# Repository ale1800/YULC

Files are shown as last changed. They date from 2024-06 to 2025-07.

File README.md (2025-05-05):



# YULC (Yes, a USB-C Led Controller)

## Current hw rev: [2.2](https://github.com/ale1800/YULC/blob/main/HW_VERSIONS.md)

## Available [here](https://aaelectronics-shop.com/)!

## You can find [here](https://aaelectronics-docs.com/documentation/yulc/yulc.html) the complete documentation.

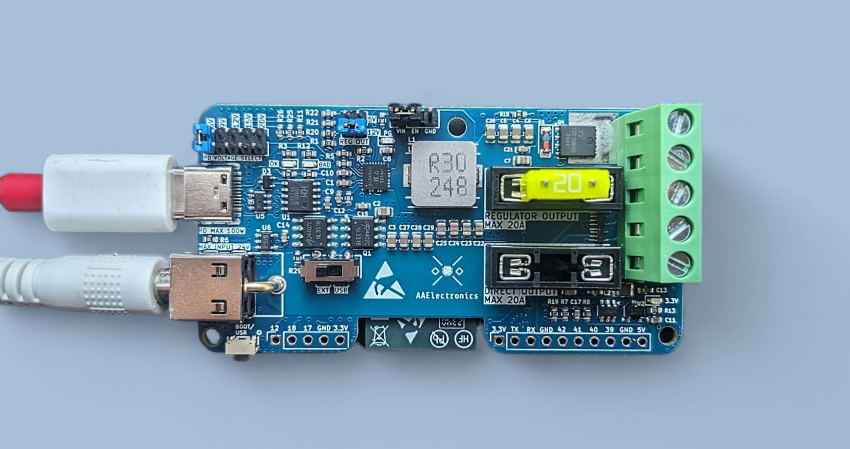
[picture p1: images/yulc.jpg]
yulc

**YULC** is your future-proof perfect mate for powering your lightings at 5, 12 or 24V. Thanks to its compact form factor, it can be placed almost everywhere, it features a lot of protections to **ensure safety for both the charger and the strips**, and in the meanwhile, **can provide a lot of juice to feed very power-hungry lights setup.** 
It also boasts an handy **built-in buck regulator** that from a maximum of 24V ensures safe 5V or 12V to your output. This mean that is also possible to use 18,19,...,24V external power supply (USB-C or barrel jack) taking advantage of their higher total power output and converting them to 5V or 12V increasing the output current.
Furthermore, on the back of the board there is a **powerful ESP32-S3, directly programmable from the USB-C**, that allows you to manage even more complex effects and to run heavy tasks.  
So, in few words, **YULC** consists in a full-featured board that can replace a lot of wiring messes, optimizing space and debug time in a reliable way.

## HOW IT WORKS

Here you can have a look to how the power path works:

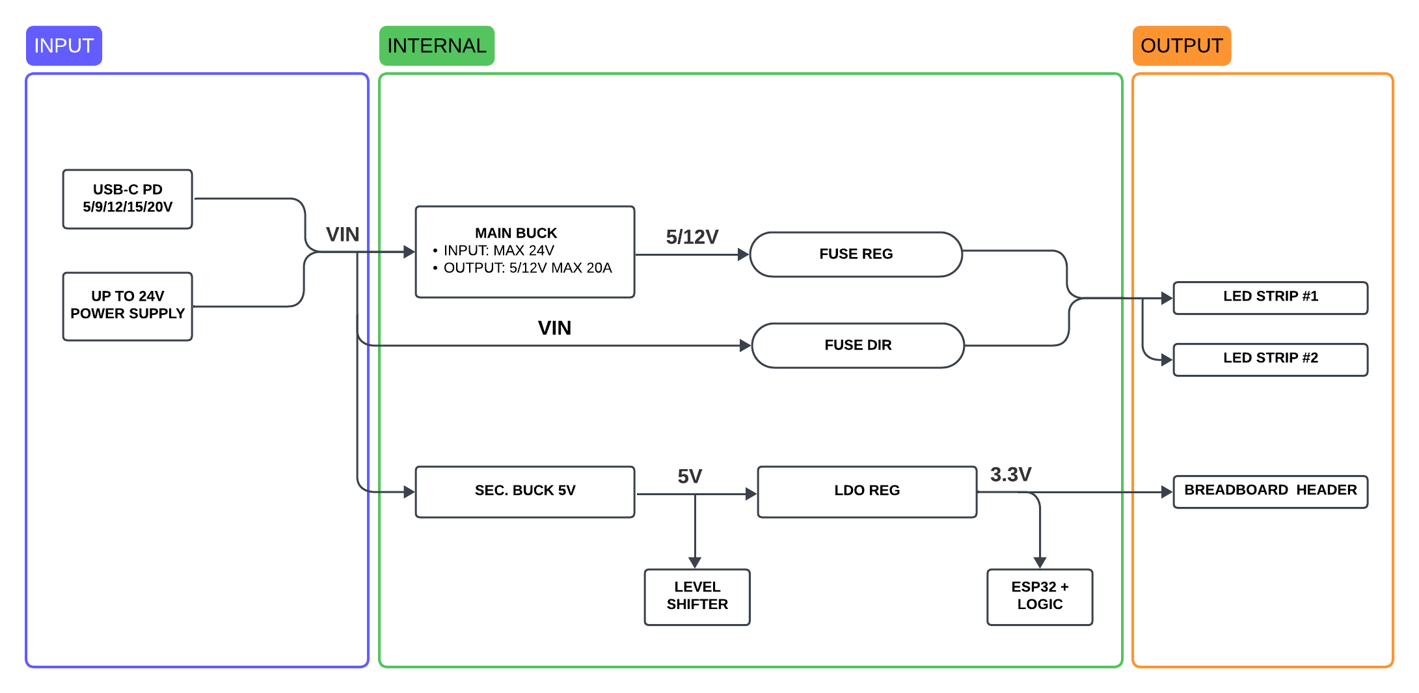
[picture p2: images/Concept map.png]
Concept map (6)


There are two power stages. The main one for the led stips and one dedicated to the ESP32

Powering all the logic and the ESP32-S3 with a dedicated secondary power stage without relying on the main one ensures that in case of a blowing fuse, everyhitng will still work as expected. So replacing the fuse on-the-fly will be the only thing you'll need to be again ready to go.

## YULC SETTINGS EXPLANATION

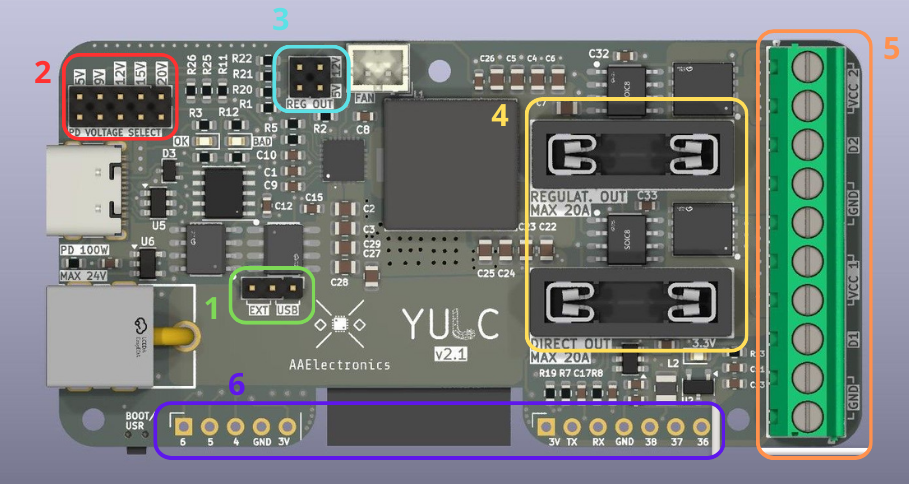
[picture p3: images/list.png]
Board


1) This is the main jumper that you have to select before anything else and before powering the board. If you join the **"EXT"** pins, YULC will be powered through the barrel jack power supply, not through the USB-C. So you can use a power supply up to 24V and then decide if you want to buck it to 5V or 12V or use it directly to the output bypassing the buck converter. With this selection, you are also able to safely program YULC through the USB-C while powering everything from the external power supply thanks to a back-to-back mosfet configuration. To do that **you have to select 5V from the PD selection voltage (2)**. There will also be those 5V on the board but they won't power anything (To prove that just disconnect the barrel jack power supply and the board will be turned off).
Instead, if you select **"USB"** pins, everything will be powered from the USB-C according to the voltage selected. 
As before, you can choose to buck the voltage to 12 or 5V or use it directly.
> [!CAUTION] 
**When selecting "USB", do not also connect the barrel jack!**.
   
2) USB-C PD Voltage selection. **Note that these voltages are the one you are asking for to the charger, not the ones you'll surely have on the board.** Selecting 20V, if the charger can provide them, the negotiation will end successfully, mosfets will let current flow and everything will be powered on. But if the charger is not able to do that, the negotiation will fail and the board will stay off. To help you debug that, the leds "OK" or "BAD" will lights up according to the negotiation result. Pay attention to the chargers you want to use. It should have a label with the list of voltages it can provide, so be sure to ask for that supported voltages, otherwise the negotiation will fail. Also consider the amount of power you need for your led strips and the power the charger can give.
**Chargers with the USB-A output will not work, even selecting 5V on YULC. Only Type-C Power Delivery chargers are compatible**
> [!IMPORTANT]  
Eg. If you have 5V strips like WS2812b and you want 6A at the output (so 30W), **be sure to ask the for a voltage/current combo the charger can offer that can give those 30W and than buck it to 5V through the converter to have the current you want at the output.**

> [!IMPORTANT]  
Be sure to select the closest combination of power and input voltage to what you need. If you need the buck IC to regulate at 5V, an input voltage of 9V or 12V will be better than a 24V from the heating point of view. The voltage difference (Vin - Vout) is smaller, so the inductor is "less stressed" -> less ripple current -> less heat. So you need the best trade-off with a quite close input voltage and enough power for your application.

3) This is the buck converter output regulation. Populate horizontally the pairs of pins according to the voltage you want to have at the output. If your input is lower or same as the output, just do not use the buck converter and route it directly but keep it populated even if you don't use it. The buck IC will automatically enter in an energy save mode when the load is really small or even is not present.
**The same voltage will be shared across the two channels**
You can source up to 20A from the IC.
> [!IMPORTANT]  
**With high watts at the output the board's temperature will increase, so please always use the given heatsinks (both for the IC and the inductor) and the 5V fan to be on the safe side.**

4) These two fuse holders are not one for channel as it could seem. The two channels share the same fuse. But there are two fuses because you have to select only one at a time according to what output you need. If you need the buck converter you have to populate the **"REGULAT. OUT"** fuse. Otherwise, if you want the input voltage routed directly to the output, populate the **"DIRECT OUT"** one.
These holders are compatible with both the standard automotive blade fuses and the mini blase fuses, but for higher currents the standard blade fuse is suggested thanks to a better contact with the holder's metal
> [!CAUTION]  
**Never populate both of them at the same time, it will short the regulator IC**.

5) YULC's has 10 output terminals, 5 for each channel: **2x Positive terminal, 2x GND terminal, 1x Data terminal**.     
Each terminal can handle up to 15A, so it's heavily suggested to use both the pairs of the positive terminal and negative terminal, to decrease the overall resistance and to inject power easier later in the strips.
Each channel is equipped with a level shifer to its data output and a high side power N-mosfet, in order to save a lot of power for longer strips in the idle state. These mosfets can also be used to control simpler strips through PWM, so you can easily control different combinations of type of strips using both the channels. **Plase attach the given heatinsks to them to keep them cool when switching high currents**

6) YULC exposes also some pins through breadboard-friendly headers. You can use these to connect buttons/microhpones/potentiometers but you can also increase the number of output channels but consider that they don't have level shifters and that you should take the power from the dedicated output terminals
   
 **GPIO Header:**
  
  |   Pin    |  Function |
  |----------|-----------|
  |  GPIO 6 |     IO    |
  |  GPIO 5 |     IO    |
  |  GPIO 4 |     IO    |
  |  GPIO 38 |     IO    |
  |  GPIO 37 |     IO    |
  |  GPIO 36 |     IO    |
  |  3V      |   Power   |
  |  GND     |  Ground   |
  |  GPIO 44   |    TX     |
  |  GPIO 43   |    RX     |
  
 **Used GPIO:**

  | Pin | Function |
  | --- | ---|
  | GPIO 0 (DO) | Boot/User Button |
  |  GPIO 1 (DO) | Led Data 1 |
  |  GPIO 2 (DO) | Led Data 2 |
  |  GPIO 47 (DO) | Mosfet 1 |
  | GPIO 21 (DO) | Mosfet 2 |
  | GPIO 7 (AI) | Fuse sense |

## YULC'S FISRT CONFIGURATION

According to your type of setup, you'll want to set YULC and strips to be powered in the the best way possibile.
Follow this steps to determine all the jumpers selection you need according to how [they work](#yulc-settings-explanation):
  
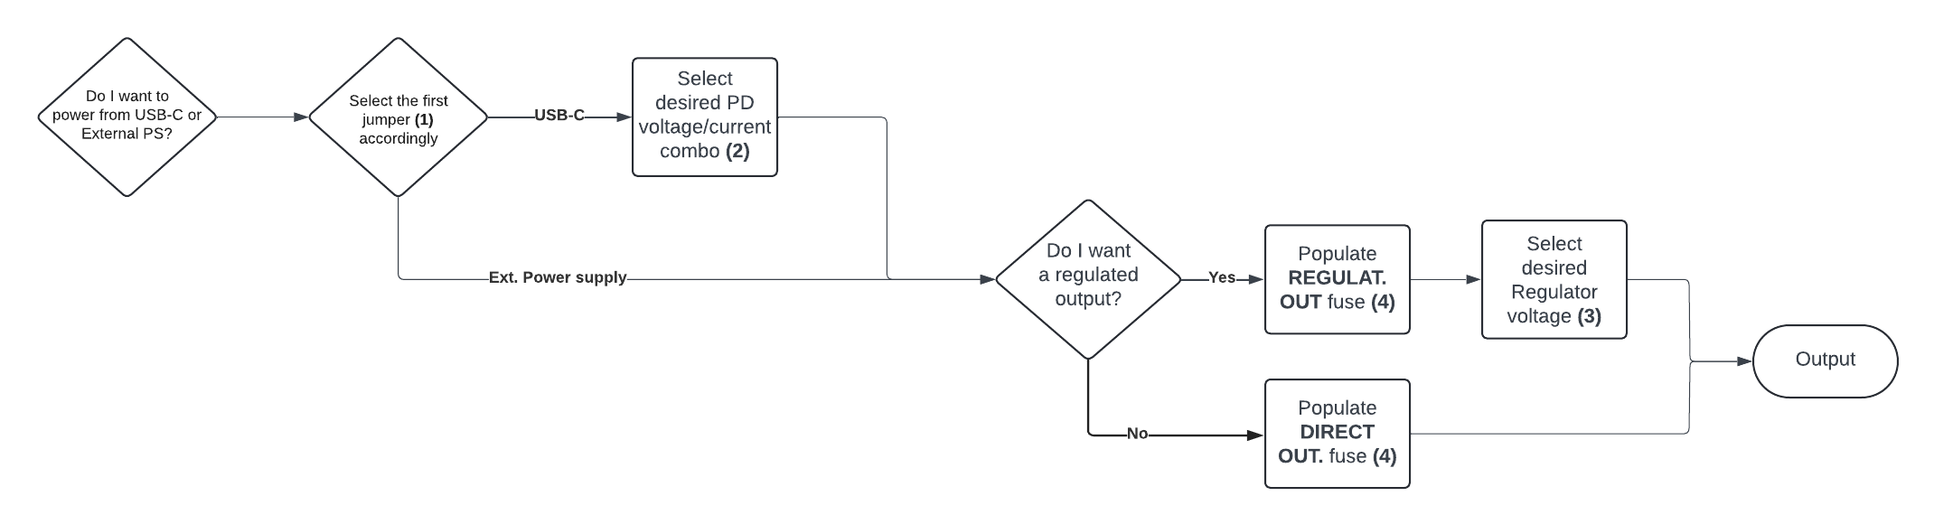
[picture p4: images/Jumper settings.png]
Settings_flow


> [!WARNING]  
**Be sure to power YULC only after you've set everything up, do not change PD and buck output voltages on the fly, neither the first jumper**

**Only after you are done with jumpers and fuse selections you can mount the [3D printed enclosure](https://github.com/ale1800/YULC/blob/main/ENCLOSURES.md), because once it's mounted, you'll have limited access to them.**

## SOFTWARE CONFIGURATION
- **YULC with [WLED](#wled)**
- ...

### WLED
Wled for YULC is a manually compiled build, based on the **v0.15.0-b5 "Kosen"**. It features 2 usermods: [Audio Reactive](https://kno.wled.ge/advanced/audio-reactive/) and [MultiRelay](https://mm.kno.wled.ge/usermods/MultiRelay/).

<center>
   <p>
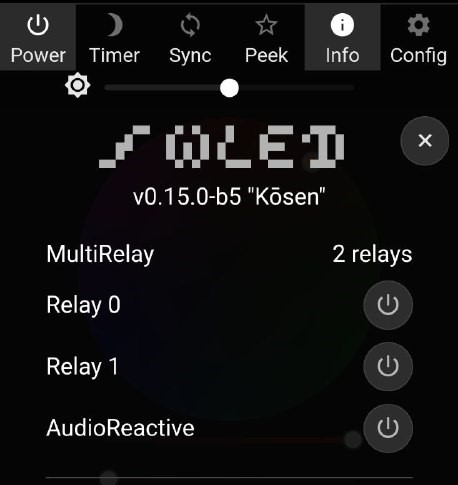
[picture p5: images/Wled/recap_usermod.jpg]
       
   </p>
</center>

**AUDIO REACTIVE**
 
Thanks to the powerful ESP32-S3, you can really take adavantage of this integration while driving complex effects on really long strip. Yuo have multiple pins on the exposed header that you can use to read an I2S microphone.

**MULTI RELAY**

Natively WLED only support one pin (usually connected to a relay) to physically turn on and off the light strips. While you can always use one of the exposed pins to wire an external relay, the built-in hardware already allows you to drive the two channels independently and each with its own power mosfet to toggle the strips. And thanks to this usermod, you can fully take advantage of it.
This is valid if you want to connect two addressable strips, but, for example, if you want to connect one digital strip and an anlog one, WLED already manage this without any external software. You would only need to set one mosfet as the main relay, and the other one as a PWM driving signal.
YULC offers a great versatility from this point of view.

So, to configure two digital strip go to **Config -> LED Preferences** and set everything up like the following picture with your own strips type and lengths. Also check **"Make a segment for each output"**
<center>
<p>
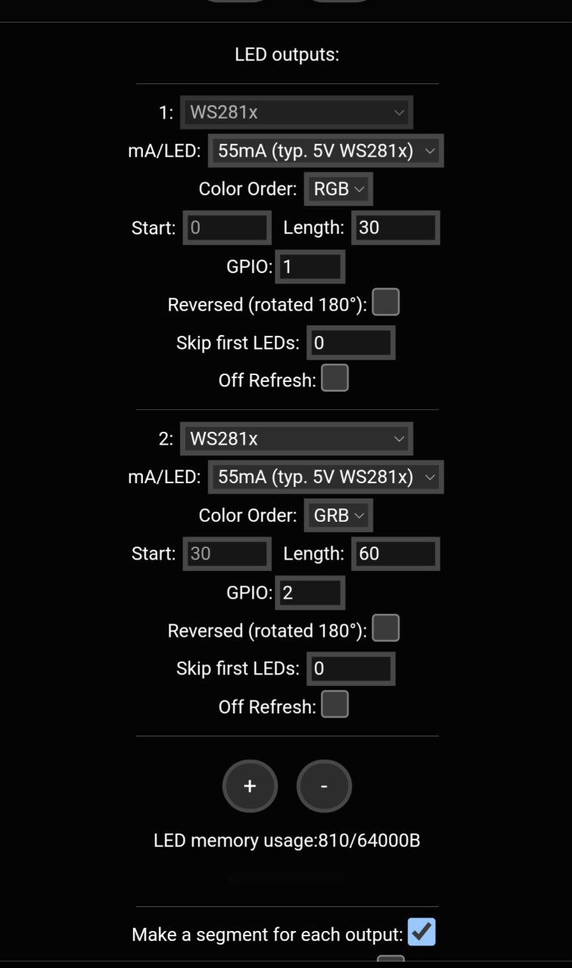
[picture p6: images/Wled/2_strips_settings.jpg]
 
</p>
</center>

Now go back **to Config -> Usermods** and, again, follow the picture, then save. This usermod has 4 pre-defined relays, but you only need the first two. **Pin 47 is linked to Channel 1** (DATA 1 on the PCB) and pin **21 to Channel 2**. Check also **"External"** on both, so we can control these relays through the dedicated APIs.
<center>
<p>
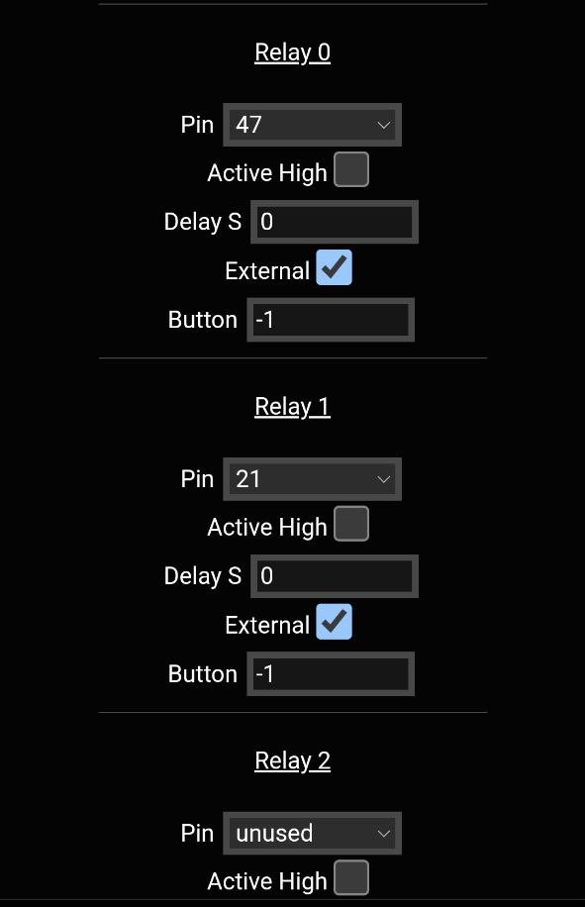
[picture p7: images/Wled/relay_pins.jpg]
 
</p>
</center>
At this point we can physically toggle both segments through built-in mosfets combining both WLED and Multi Relay JSON API. Keep in mind that the WLED main button will still turn off all the segments at once.
The calls you need are:

```yaml
//Switching on the mosfet #0 to power the first segment/strip
curl -X POST -H "Content-Type: application/json" -d ''{"MultiRelay":{"relay":0,"on":true}}'' "http://your-ip-address/json"

//Turning on "software" the segment with ID #0
curl -X POST -H "Content-Type: application/json" -d ''{"seg":[{"id":0,"on":true}]}'' "http://your-ip-address/json/state" 

```
When switching on you'll want to physically turn on the strip before turning on via software. Instead, when switching off, it would be better to reverse the sequence.
Basically there should not be data signals to led strips while they are physically disconnected from the power supply.

If you are an Home Assistant user, you can easily integrate these controls as **light** entities using some shell commands:

```yaml
shell_command:
  strip_1_on: 'curl -X POST -H "Content-Type: application/json" -d ''{"seg":[{"id":0,"on":true}]}'' "http://your-ip-address/json/state"'
  strip_1_mos_on: 'curl -X POST -H "Content-Type: application/json" -d ''{"MultiRelay":{"relay":0,"on":true}}'' "http://your-ip-address/json"'
  strip_1_off: 'curl -X POST -H "Content-Type: application/json" -d ''{"seg":[{"id":0,"on":false}]}'' "http://your-ip-address/json/state"'
  strip_1_mos_off: 'curl -X POST -H "Content-Type: application/json" -d ''{"MultiRelay":{"relay":0,"on":false}}'' "http://your-ip-address/json"'
  strip_2_on: 'curl -X POST -H "Content-Type: application/json" -d ''{"seg":[{"id":1,"on":true}]}'' "http://your-ip-address/json/state"'
  strip_2_mos_on: 'curl -X POST -H "Content-Type: application/json" -d ''{"MultiRelay":{"relay":1,"on":true}}'' "http://your-ip-address/json"'
  strip_2_off: 'curl -X POST -H "Content-Type: application/json" -d ''{"seg":[{"id":1,"on":false}]}'' "http://your-ip-address/json/state"'
  strip_2_mos_off: 'curl -X POST -H "Content-Type: application/json" -d ''{"MultiRelay":{"relay":1,"on":false}}'' "http://your-ip-address/json"'
    
light:
  - platform: template
    lights:
      strip_1:
        turn_on:
          - service: shell_command.strip_1_mos_on
          - service: shell_command.strip_1_on
        turn_off:
          - service: shell_command.strip_1_off
          - service: shell_command.strip_1_mos_off
      strip_2:
        turn_on:
          - service: shell_command.strip_2_mos_on
          - service: shell_command.strip_2_on
        turn_off:
          - service: shell_command.strip_2_off
          - service: shell_command.strip_2_mos_off
```

Now you have two completely separated strips from every point of view.

ha-wled
## License
License

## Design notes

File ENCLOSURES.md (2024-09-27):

## INSTALLING THE ENCLOSURE

This board does not have a "full closed" enclosure, because it needs a lot of air flow while stressing it with a lot of output current. So actually the "enclosure" will consists in two pieces: a simple flat base to screw to YULC with 3 M2 screws and the fan holder.

## STEP 1

First attach the inductor heatsink (the biggest one) as far to the right as possible, almost touching the fuse holder. Doing this way there is enough space for the regulator heatsink.

> [!IMPORTANT]  
Pay attention to place the heatsink in a way that it does not touch any other components, in particular the regulator IC one

In the end you can place the two heatsinks for the mosfet and then mount YULC on the base locking it in place with the help of the three smallest M2 screws
<center>
<p>
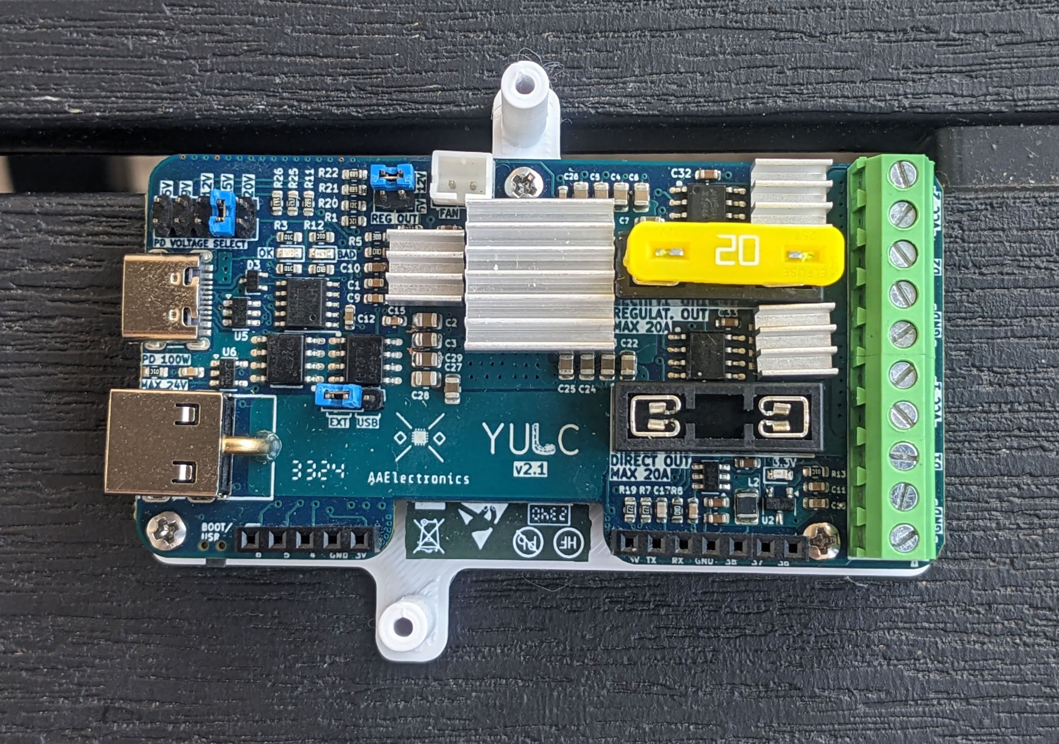
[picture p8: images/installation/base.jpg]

</p>
</center>

## STEP 2

Use other 4 M2 screws to mount the facing down fan on top of the holder and then connect it to YULC thorugh the dedicated JST connector. 
<center>
<p>
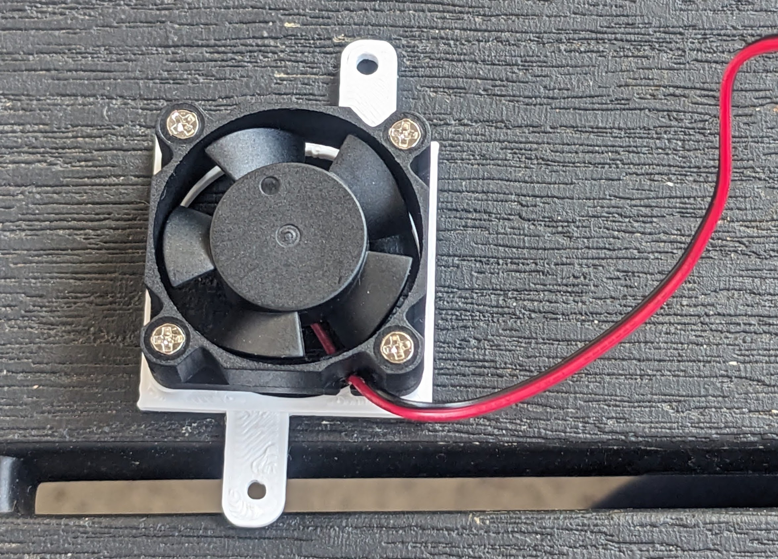
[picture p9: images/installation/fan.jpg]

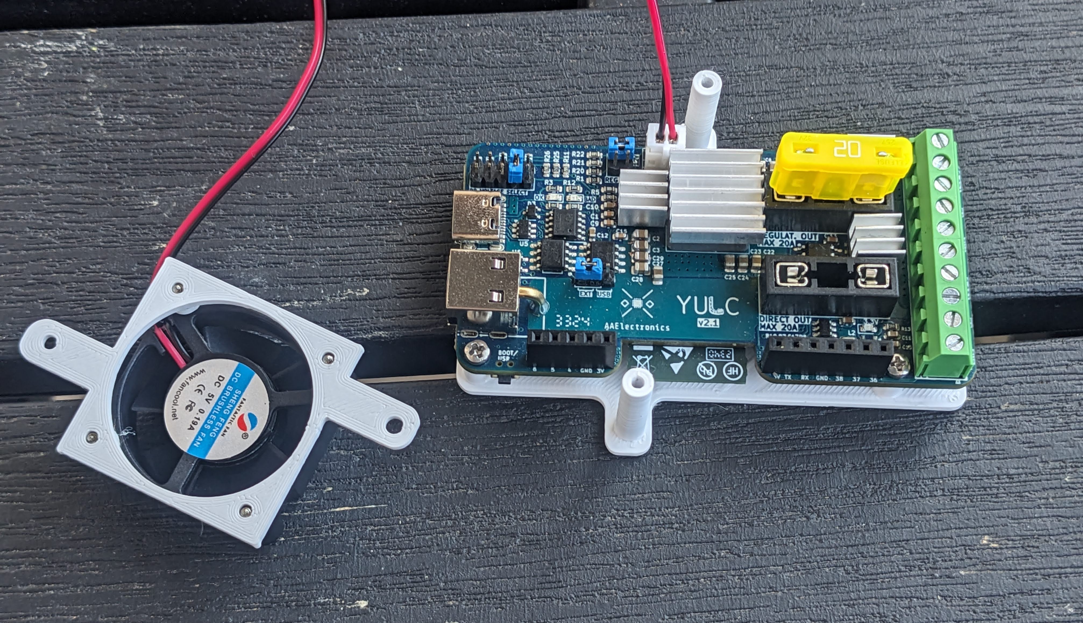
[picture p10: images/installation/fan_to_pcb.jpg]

</p>
</center>

## STEP 3

Now, with the help of the two longer screws, connect the fan holder to the two pillars of the base

<center>
<p>
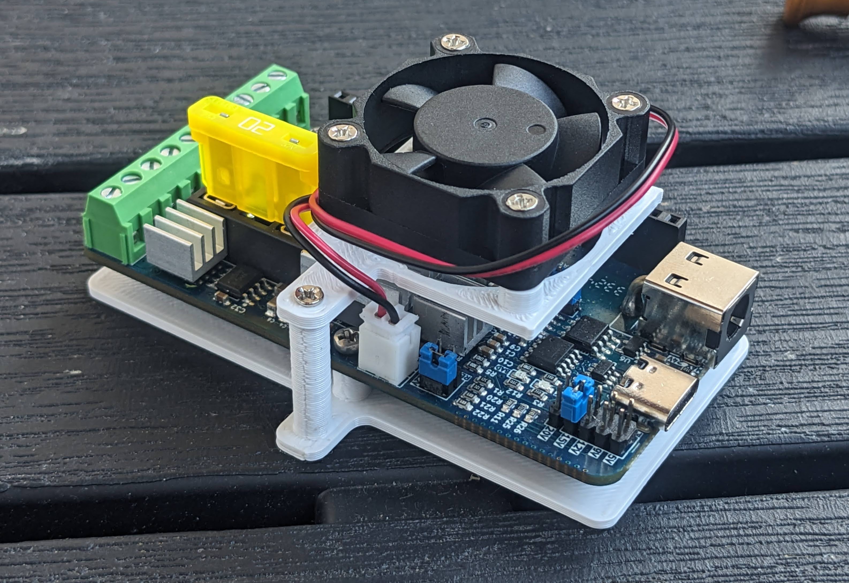
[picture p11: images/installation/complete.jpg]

</p>
</center>

Your YULC is completely assembled, you can proceed with the [software configuration](https://github.com/ale1800/YULC/tree/main?tab=readme-ov-file#software-configuration)

## BONUS

### DIN BRACKET
The base has two more holes for M2 screws that can be used to design other types of support, like a din-mounting bracket, taken from [thingiverse](https://www.thingiverse.com/thing:2613804) and modified a bit.

<p>
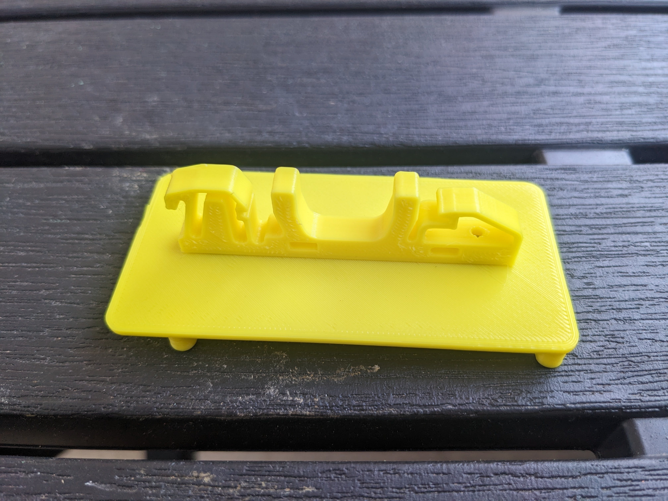
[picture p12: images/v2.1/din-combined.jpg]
 
</p>

If you want to install something like this, you have to do that before [STEP 1](#step-1)

### INMP441 MIC ADAPTER

If you would like to use the INMP441 microphone breakout board in combination with the Sound Reactive usermod, you can find [here](https://github.com/ale1800/YULC/blob/main/Schematic/mic.zip) the gerber file of the tailor-made adapter.

<center>
<p>
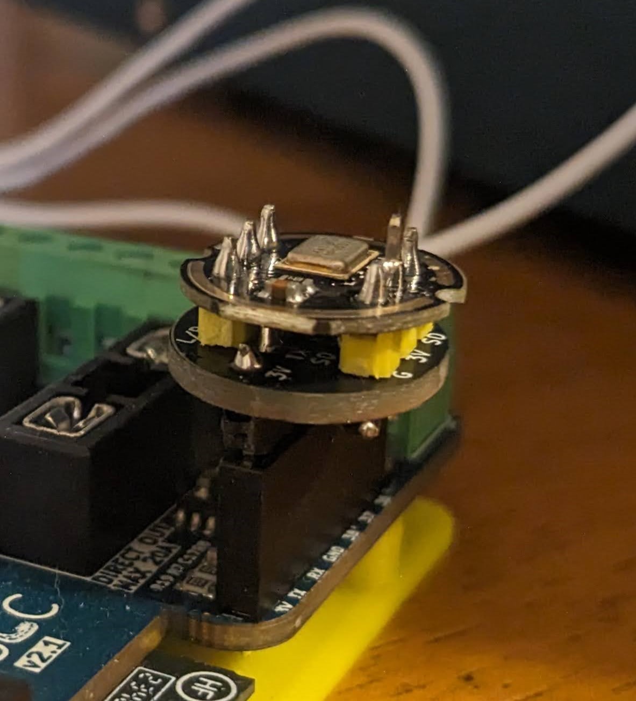
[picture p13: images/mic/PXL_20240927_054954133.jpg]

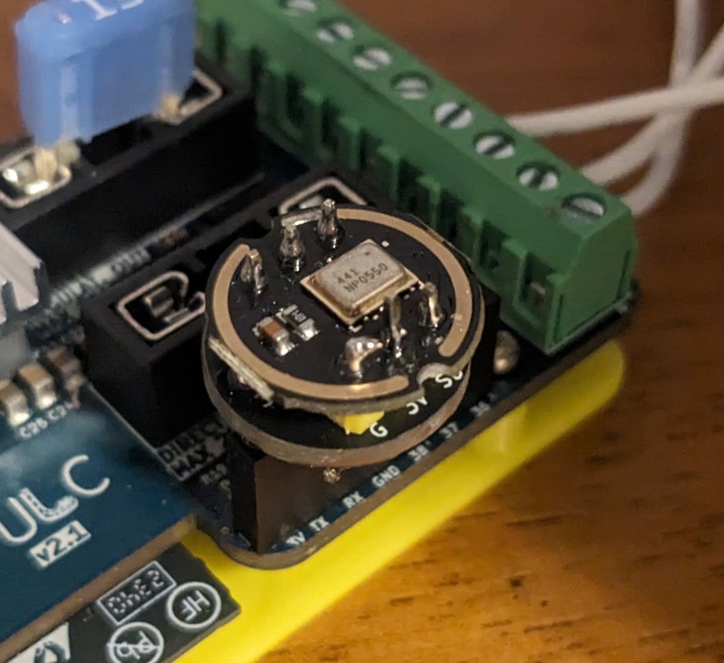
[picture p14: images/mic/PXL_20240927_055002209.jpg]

</p>
</center>

It uses the following pins:
| YULC Pin | INMP441 Pin |
| --- | ---|
| 3V | 3V |
|  GPIO 43 (TX) | SD |
|  GPIO 44 (RX) | WS |
|  GND | GND, L/R |
| GPIO 38 | SCK |

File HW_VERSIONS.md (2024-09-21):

## YULC v1.0
<center>
<p>
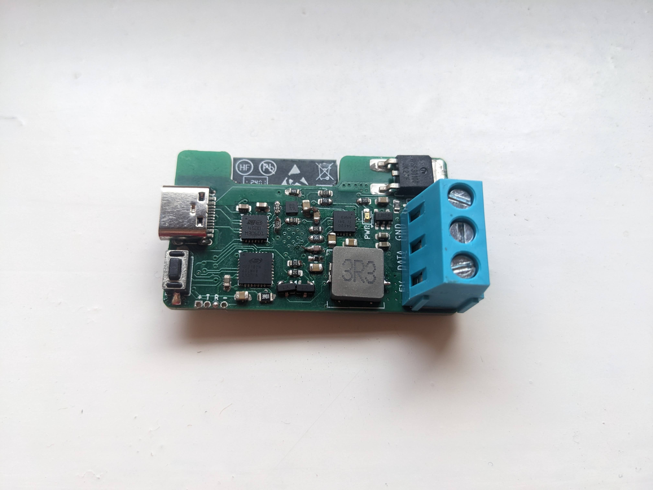
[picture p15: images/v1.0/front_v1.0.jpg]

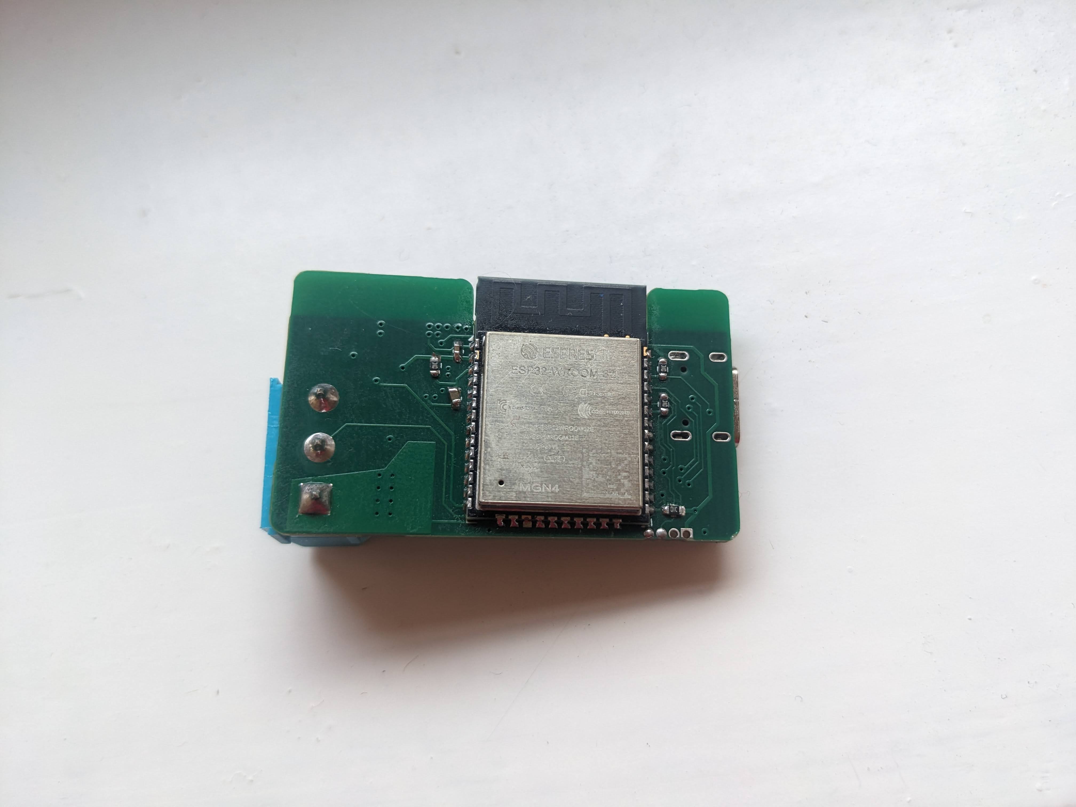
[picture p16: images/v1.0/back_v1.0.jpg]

</p>
</center>
This first version consists in a single channel 5V Led controller.

It uses the STUSB4500 IC from ST to handle the PD delivery. This module must is configured by the ESP32 using I2C protocol through which is set the voltage the IC should ask for to the chargers.
It can ask up to 20V and convert to 5V to the output.

The microncontroller is an ESP32-WROOM-32E and using an CP2102 it can be programmed through the USB-C port.

There should also be a mosfet to turn off the strips but the footprint was the wrong one, so that does not work.

## YULC v2.0
<center>
  <p>
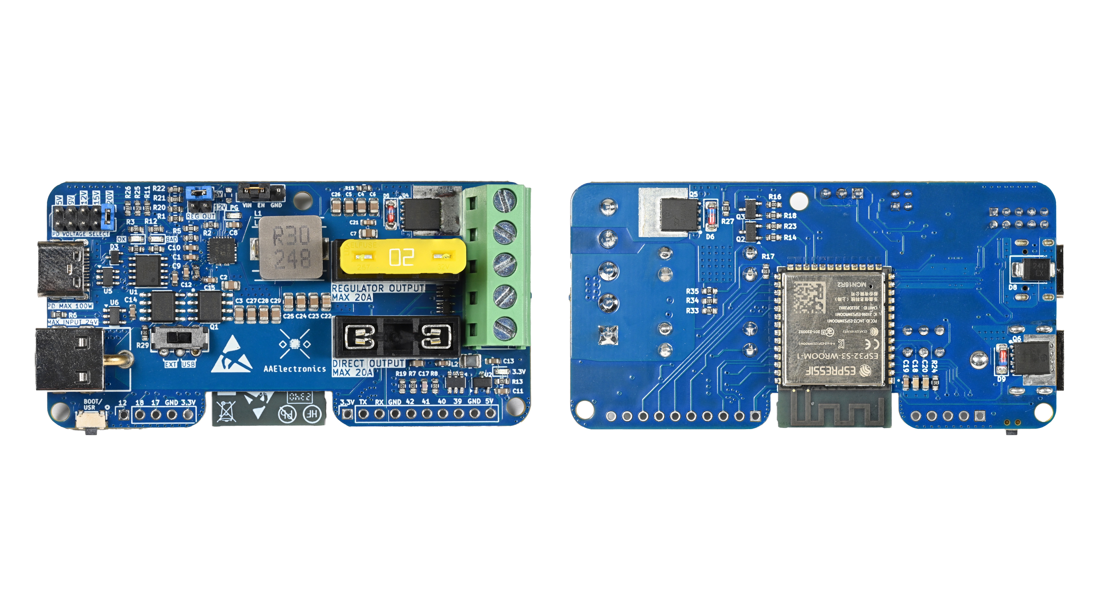
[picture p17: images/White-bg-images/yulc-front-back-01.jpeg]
    
  </p>
</center>
This version comes with a lot of upgrades compared to the v1.0:

- 2 Channels
- Newer ESP32-S3
- Dual power supply possibility
- 5V or 12V regulated output (or direct)
- Fuses
- Level shifters
- Able to power from ext. power supply and program the ESP at the same time.
- Mosfets for both channels

Everything works correctly excepts for the mosfets. THey switch the negative terminal and, while it's working for analog strips, it does not work for the dgital ones. The current must find another path to GND, making mosfets useless

## YULC v2.1
<center>
  <p>
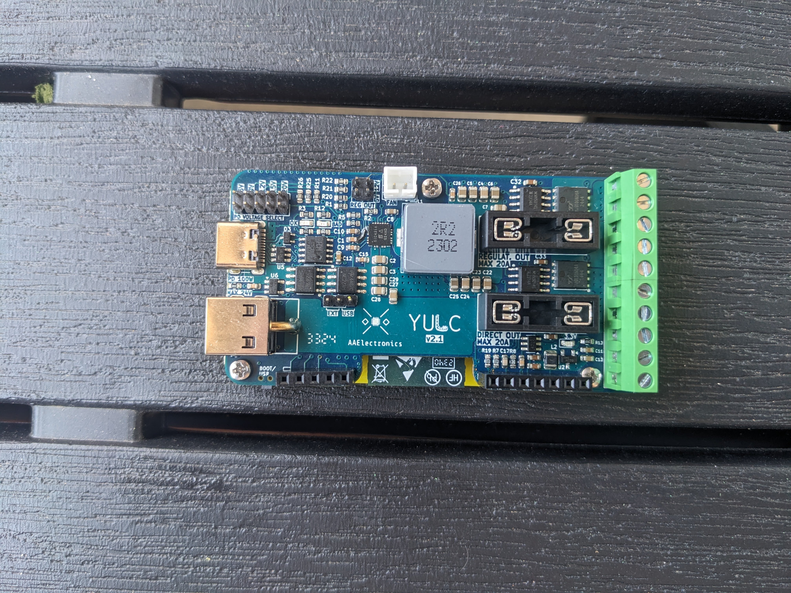
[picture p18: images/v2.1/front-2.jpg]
    
  </p>
</center>

In this version I fixed some small things. Compared to v2.0, the two mosfets are now on the top layer, to be able to put the heatsink on both. I also re-arranged the two P-Mosfets on the USB-C Power bus, to allow a better routing for the input capacitors of the main buck converter. Now they are much closer, leading to a better overall behaviour of the IC.

The inductor has changed and I also added the JST connector for the 5V fan.

The 3 mounting holes are now standardized, and M2 screws fit very well.

Now the mosfets switch the positive side thanks to two MX5014S, an high side mosfets driver. It's quite cool because its connections are really simple, it can work up to 50V; it does not need an external bootstrap capacitor and can stay on for ever, so 100% duty cycle without any problems.

Thanks to this IC, mosfets now works flawlessly for both digital and analog strips.

Now there are more output terminals to reduce the overall resistance of the serie **BUCK IC + POWER INDUCTOR + FUSE + TERMINALS**. With the new inductor and more parallel terminals, the resistance dropped from around 25 mOhm v2.0 to 12/13 mOhm. Testing this new version, with a current of 19A, I have around of 250/300mV drop compared to 400mV of the v2.0. So From 5V to 4.7V instead 4.6V

**For the test, the input voltage is 19V and it's regulated down to 5V through the buck converter.**
<center>
  <p>
    <figcaption>Output resistance v2.0</figcaption>
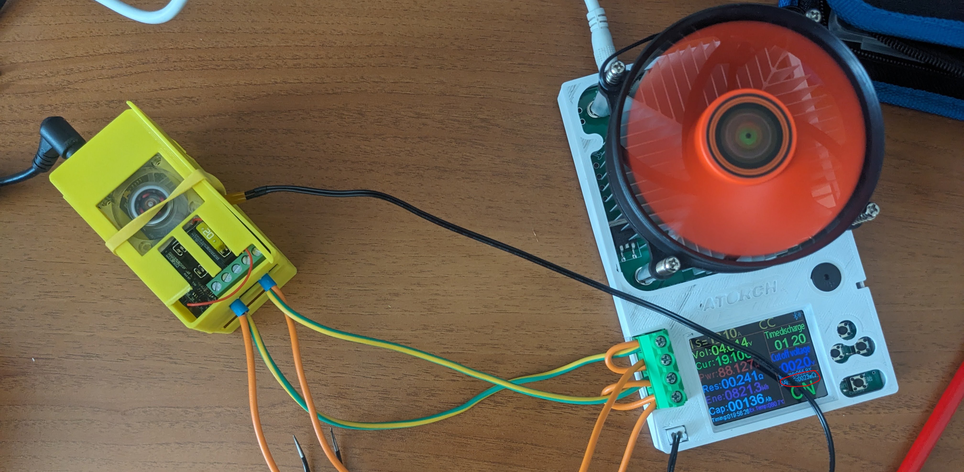
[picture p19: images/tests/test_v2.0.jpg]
    
  </p>
</center>
<center>
  <p>
    <figcaption>Output resistance v2.1</figcaption>
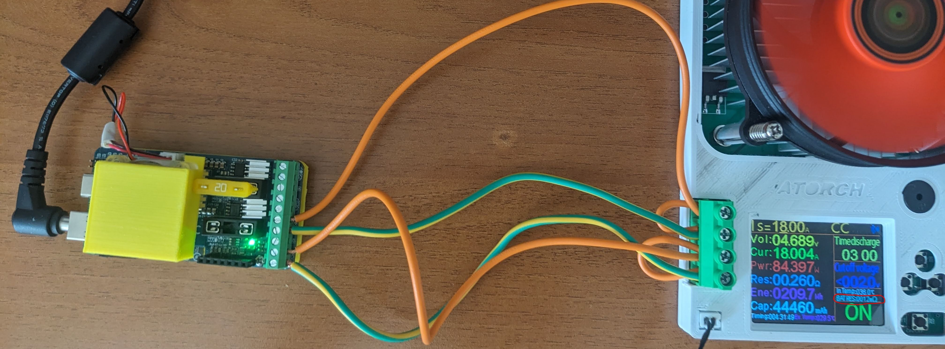
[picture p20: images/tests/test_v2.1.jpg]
    
  </p>
</center>

This version also performs really well with 12V output converting a lot of power. Here it's converting 164 W from a 24V input keeping an overall temperature < 50°C after a 4hrs long test. The output resistance is even less than the other test (11mOhm vs 12/13mOhm). Probably less ripple current in the inductor.

<p>
    <figcaption>24V Input -> 12V@14A Output v2.1</figcaption>
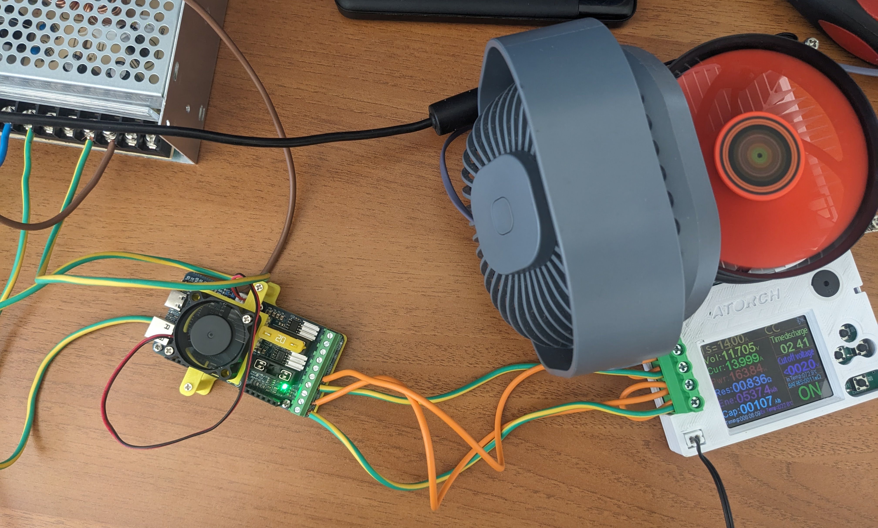
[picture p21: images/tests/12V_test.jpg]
    
</p>

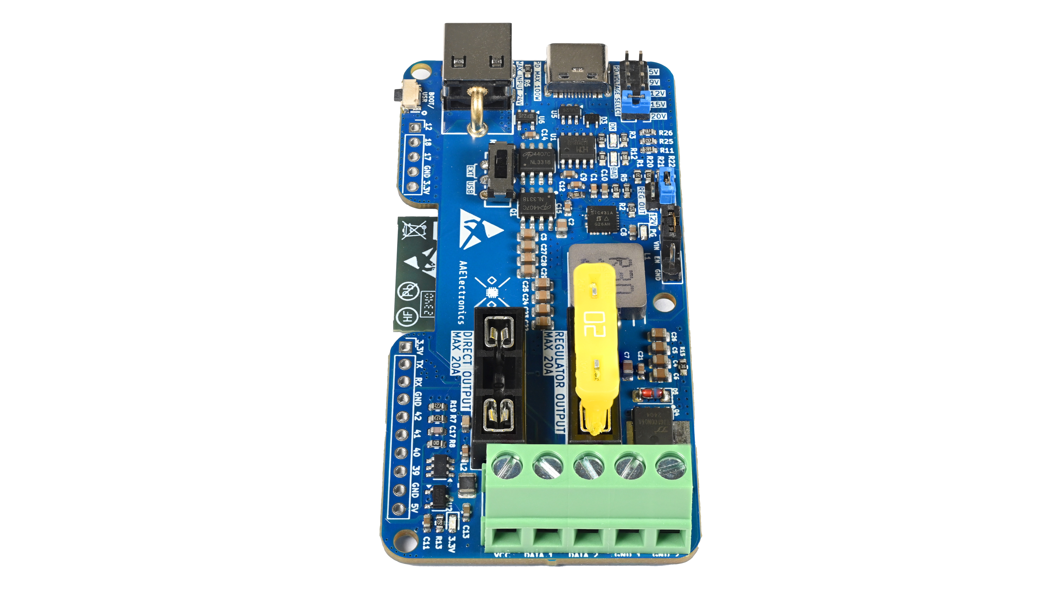
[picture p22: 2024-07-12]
images/White-bg-images/yulc-angle-03.jpeg

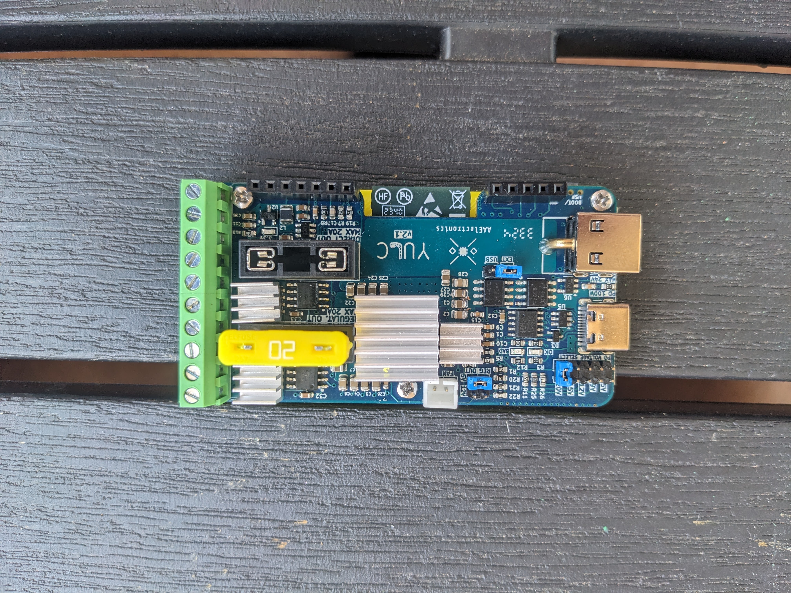
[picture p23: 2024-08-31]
images/v2.1/yulc_v2.1.jpg

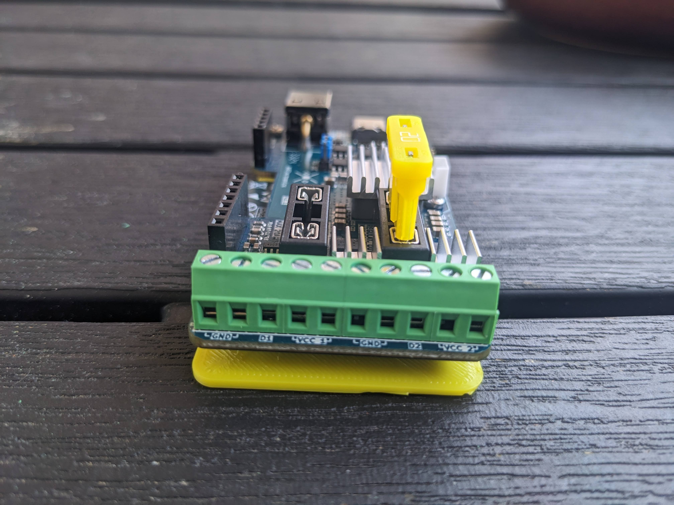
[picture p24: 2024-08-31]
images/v2.1/terminal.jpg

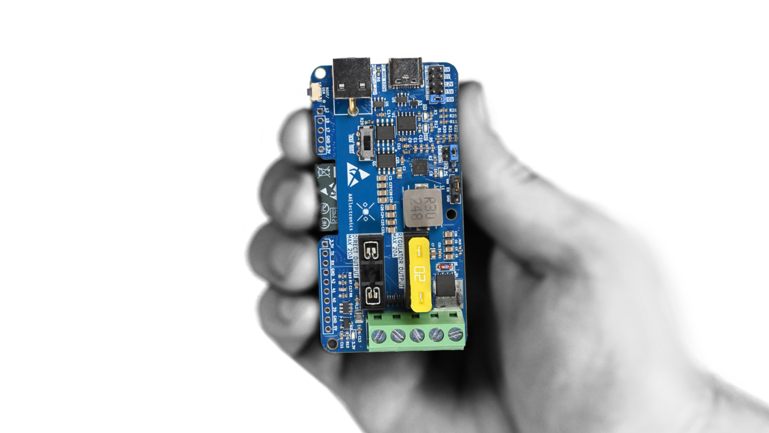
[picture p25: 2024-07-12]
images/White-bg-images/yulc-scale-01.jpeg

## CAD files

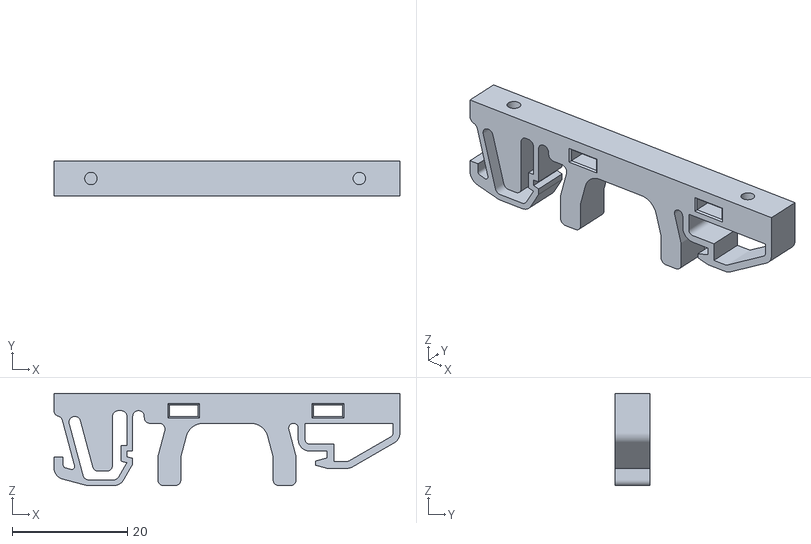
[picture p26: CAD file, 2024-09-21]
3D&Dimensions/din.stl
60.0 x 6.00 x 16.0

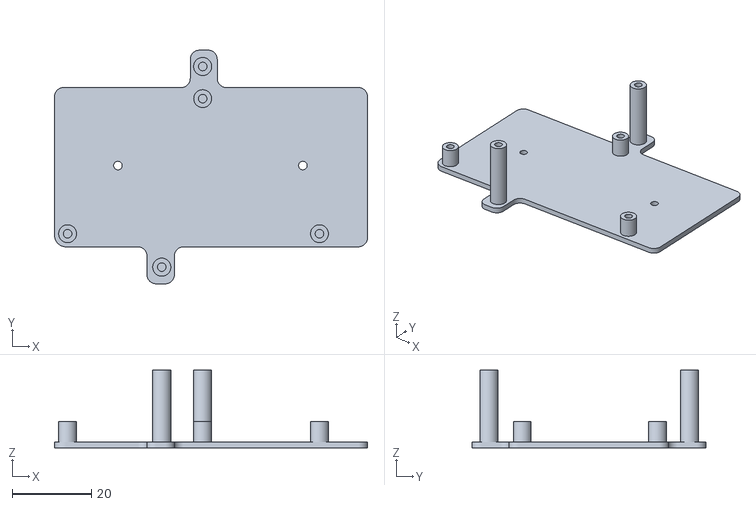
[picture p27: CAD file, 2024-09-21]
3D&Dimensions/base.stl
78.8 x 58.8 x 19.6

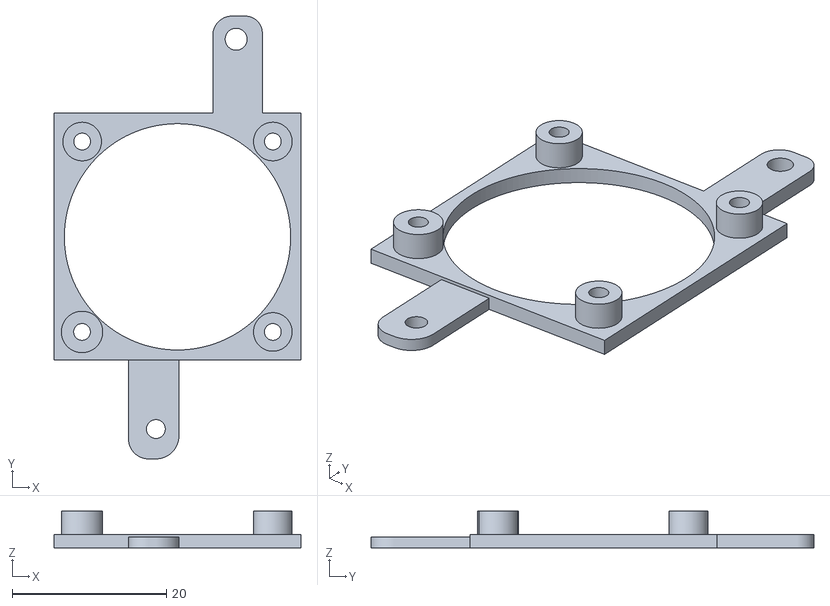
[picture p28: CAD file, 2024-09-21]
3D&Dimensions/fan-holder.stl
32.0 x 57.4 x 4.75

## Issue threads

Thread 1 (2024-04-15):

Design options: consider an S3?

robertlipe, 2024-04-15:
This is awesome!

I'm on mobile, so reading the .Sch is hard, but I think i see esp32-wroom-32d which is the legacy module.

If you would change to ESP32-S3 (exp. With more PSRAM) you'd have a more capable board. You could also eliminate serial bridge and get jtag with no extra pads or buffers. The USB could be used as any USB type (like a disk) or as a host (attach a keyboard). You might be able to get the 8MB PSRAM/16 MB Flash modules for not a lot more than the bom cost of the serial/USB bridge and needed additional transistors to make reset work on trailing edge of dtr and pulse EN. The CPU is also more efficient per clock and has more powerful instructions handy in this world doe FFT, like doing beat detection, as well as offering better memory model with less goofy fragmentation and fewer restrictions on where you can DMA to and from.

Element

Atomic14 has a YouTube video showing a super minimal S3 build it was a USB socket, lvdo, maybe one cap for the ENable signal on power up and ... not much more. (Edit: https://youtu.be/tQ0dL_9M1wI?si=FmXgR3vD-N_fcYg2 - and I'll admit that for a production board, I probably wouldn't chip quite so deeply. Decouplers actually DO have a purpose, but his underlying point that you can make a S3 with USB from almost nothing is legit.)

As disclosure, you could go S2 and get most of those benefits, but only on a single core. C3 is dirt cheap, but only single core and has a completely different arch, being 160Mhz RISC-V instead of 240Mhz XTENSA. While that may sound slower, they're more of a draw but some projects may not support single cores.

As a stuffing option, allow the external WiFi version and, for crazy talk, some screw terminals and a few diodes to stop people from using both, allow external DC from a random DC source that's bucked to power the esp32 and passed through to the rails of the strip. Same board, populated different ways, no real cost unless it results in fewer boards per panel.

If your chosen buck/boost could get to 24V (or your PD was so equipped, which seems likely in laptops and less so in a phone charger) you'd have an advantage of being able to run longer power runs without needing injection. Budget a GPIO, resistor, led to help figure out if their random USB-C source actually has PD and at the requested wattage combination. The industry has done a terrible job of teaching consumers what voltage any given USB source will actually source.

Without seeing the schematic,. I'll say that this is pretty close to a board I've considered building. Usb-c is just the way to go. I'm glad to see you tackling this! (So I don't have to. 😉)

This isn't meant to be terrifying feedback and when I'm near a computer again,. I can perhaps even help with some of the above as it's hopefully clear that I've already been thinking about this for a while. I'm not an EE, but I may have some helpful skills.

Even if you ignore everything I've just typed, I'm likely to buy/build at least a few boards in this space this year, so I really do think you're onto something here!

ale1800, 2024-04-15:
Hello @robertlipe, thanks for your your great feedback!

I uploaded the pdf file of the schematic. The module is the ESP32-WROOM-32E, that should still be in production. I know it's quite old, but it's still the only ESP32 to support Wifi and both Classic Bluetooth and BLE and it provides fully compatibility with the most important open source firmware like ESPHome and WLED. On the other hand the advantage of removing all the serial parts is relevant, as the fastest processor that maybe could help for some effects or something similar. Honestly I don't know if it will be a commercial product or not, at the moment is a personal project. in that case I will seriously consider the switch (maybe the s3 mini?)

In the same case i will try to provide more power at the output, and the power injection is a thing I should keep in mind. I can see that a lot of people use really long strips, so pushing the PD to 24V would be really useful.

I think that the external DC is a good catch, just as a "classic" alternative to the USB-C. Maybe I could also add another terminal for a second independent strip led?

Thanks very much for your advices!

ale1800, 2024-04-16:
Sorry, when you say "If you build some", do you mean the 44 pin breakout board or my board with the S3?

Regarding the input, a DC5521 would be absolutely useful, but I think that if someone need a board with that input, should go with the Quinled boards. They are made for that. I think mine would be more expensive and "without reviews" compared to the others.

I checked the WCH board and are quite interesting! My only concern is about if these IC would be reliable as the STUSB4500?

I really appreciate your time to provide valuable suggestions!

ale1800, 2024-04-16:
I wasn't aware those board were from WCH. Good to know! Based on your experience, is the esp32 s3 native usb reliable? Because, like for the S2, I found a lot of people complaining about it. Last year I tried two ESP32 S2 mini dev board with the USB-C and I've never been able to program them. I also read that all the esp-web-tool do not work very well with the native usb. I always chose the WROOM-32E because of this and software compaitiblity in general

ale1800, 2024-04-17:
So it seems that the native USB needs a bit more attention compared to the "external" one. I will think about that and give it a try. Thanks for your really detailed explanation! I can confirm that the S3 module's price is the same as Wroom-32E + cp2102n + transistors. Swapping them seems worthy saving a lot of space.

ale1800, 2024-04-25:
Hi @robert! Can I ask you the reason why with 24V I would not need the power injection? I always have 5V at the input of the strip

ale1800, 2024-04-29:
Oh ok, Now I got it. Yes I could some jumper to select the output voltage from the buck converter. It's just 2 or 3 more resistors. Does KnightDriver have some mqtt support to use with Home Assistant or other platforms?

ale1800, 2024-05-01:
Ok, thanks. Good to know👍

ale1800, 2024-05-10:
Hi @robertlipe! Where can I PM you? Could you give me your email address?

Thanks!

Closed 2024-05-28.

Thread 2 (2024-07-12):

Broken img tags in top-level page

robertlipe, 2024-07-12:
https://github.com/ale1800/YULC/tree/main?tab=readme-ov-file

links out to
https://github.com/ale1800/ESP32-board/assets/53172176/34b24297-1c93-43cd-b487-1ca270770319
and
https://github.com/ale1800/ESP32-board/assets/53172176/7c49a46b-c15e-45c9-bb84-2c160c00b566

...but those seem to not exist.

ale1800, 2024-07-12:
Yes, I just dropped them in the readme file. I'll add all of them in folder
images

Il giorno ven 12 lug 2024 alle ore 19:17 Robert Lipe <
***@***.***> ha scritto:

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

Closed 2024-09-26.

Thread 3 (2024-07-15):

WLED enabled?

Tim-The-Woodsman, 2024-07-15:
First and foremost: that thing is great, thank you! I'm doing stuff like this, but hillbilly style, bulky and ugly. I love this project!

I'm just wondering if it'll be able to run WLED, I'm terribly lazy and my last FastLED project has been a while.

Love it ❤️

ale1800, 2024-07-15:
Hello, thank you very much! Yes, it can run WLED. Officially, the ESP32-S3 is still in an experimental stage, however actually I'm still manually compiling some builds for the board and it seems to work quite well.

Tim-The-Woodsman, 2024-07-16:
That's great ❤️

I'll take ten 😄

Closed 2024-09-26.

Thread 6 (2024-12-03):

Faulty yulc controller?

heidepiek, 2024-12-03:
Got my yulc controller yesterday. Today I was going to mount it in the printed case and try it, but I run into a problem. The controller is not seen by the computer! Have all the drivers on the computer. Have tried multiple usb cables, even tried it on another pc. But the esp is not seen! If I take another esp32 s3 with the same cables and on both pc`s it is immediately recognized in the device manager. Also tried holding down the boot button when i plug the usb into the pc. Now it stops for me, tried everything. Faulty yulc controller?

Regards Harrie
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

ale1800, 2024-12-03:
Hi! Is your cable usb-A to usb-C? If yes, it's normal is not booting. Because you need a power delivery source. Do you see the green led on the board? Or only the red one?

heidepiek, 2024-12-03:
Only the red one . It is a usb-A to usb-C cable i use. I only plugged the usb in and not another power source.

ale1800, 2024-12-03:
> Only the red one . It is a usb-A to usb-C cable i use. I only plugged the usb in and not another power source. What do you mean by it needs a power delivery? I don`t have any leds attached. I thought i have to program it first.

Ok, that's why. As I said you have to use a usb-C to usb-C cable from a power delivery brick / laptop port to power it. If you only have usb-A you need to power the board with an external power supply and changing the jumper to "ext". In the [documentation](https://aaelectronics-docs.com/documentation/yulc/yulc.html) everything is explained if you need more information

heidepiek, 2024-12-03:
Sorry alessandro, I don't want to destroy the board right away due to incompetence, so was a little careful with power connection . I have the board running.  Changed the pinout and voilla. This is new to me!  I thought I had to connect the usb and I can program it. So you can't take a regular usb charger of 2A and power the board through the usb (nor through the pc usb). I have a few phone chargers lying around with 1xusb-a and usb-c connection and and 2x usb-a. But that doesn't work. I now understand that if you want to program the board you have to power the board externally and then hook it up to your pc. I am going to read the documentation again.

Greetz Harrie

ale1800, 2024-12-03:
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

Yes, so if you only have USB-A ports on your laptop you need the external power supply. But if your laptop already has a usb-C port, you can both power and program the board with it. Because 99% that port will handle the power delivery, even with only 5V. For example my laptop can't give anything more than 5V from it's usb-c, but those 5V are PD compatibile.

Closed 2024-12-03.

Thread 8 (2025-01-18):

Discord button invalid

krbaker, 2025-01-18:
The discord button in the readme is coming up invalid for me when I click it or copy into discord

ale1800, 2025-01-19:
Thanks for reporting me. I'm fixing it. This is the new invite https://discord.gg/Rk8EsMbcQk

Closed 2025-02-14.

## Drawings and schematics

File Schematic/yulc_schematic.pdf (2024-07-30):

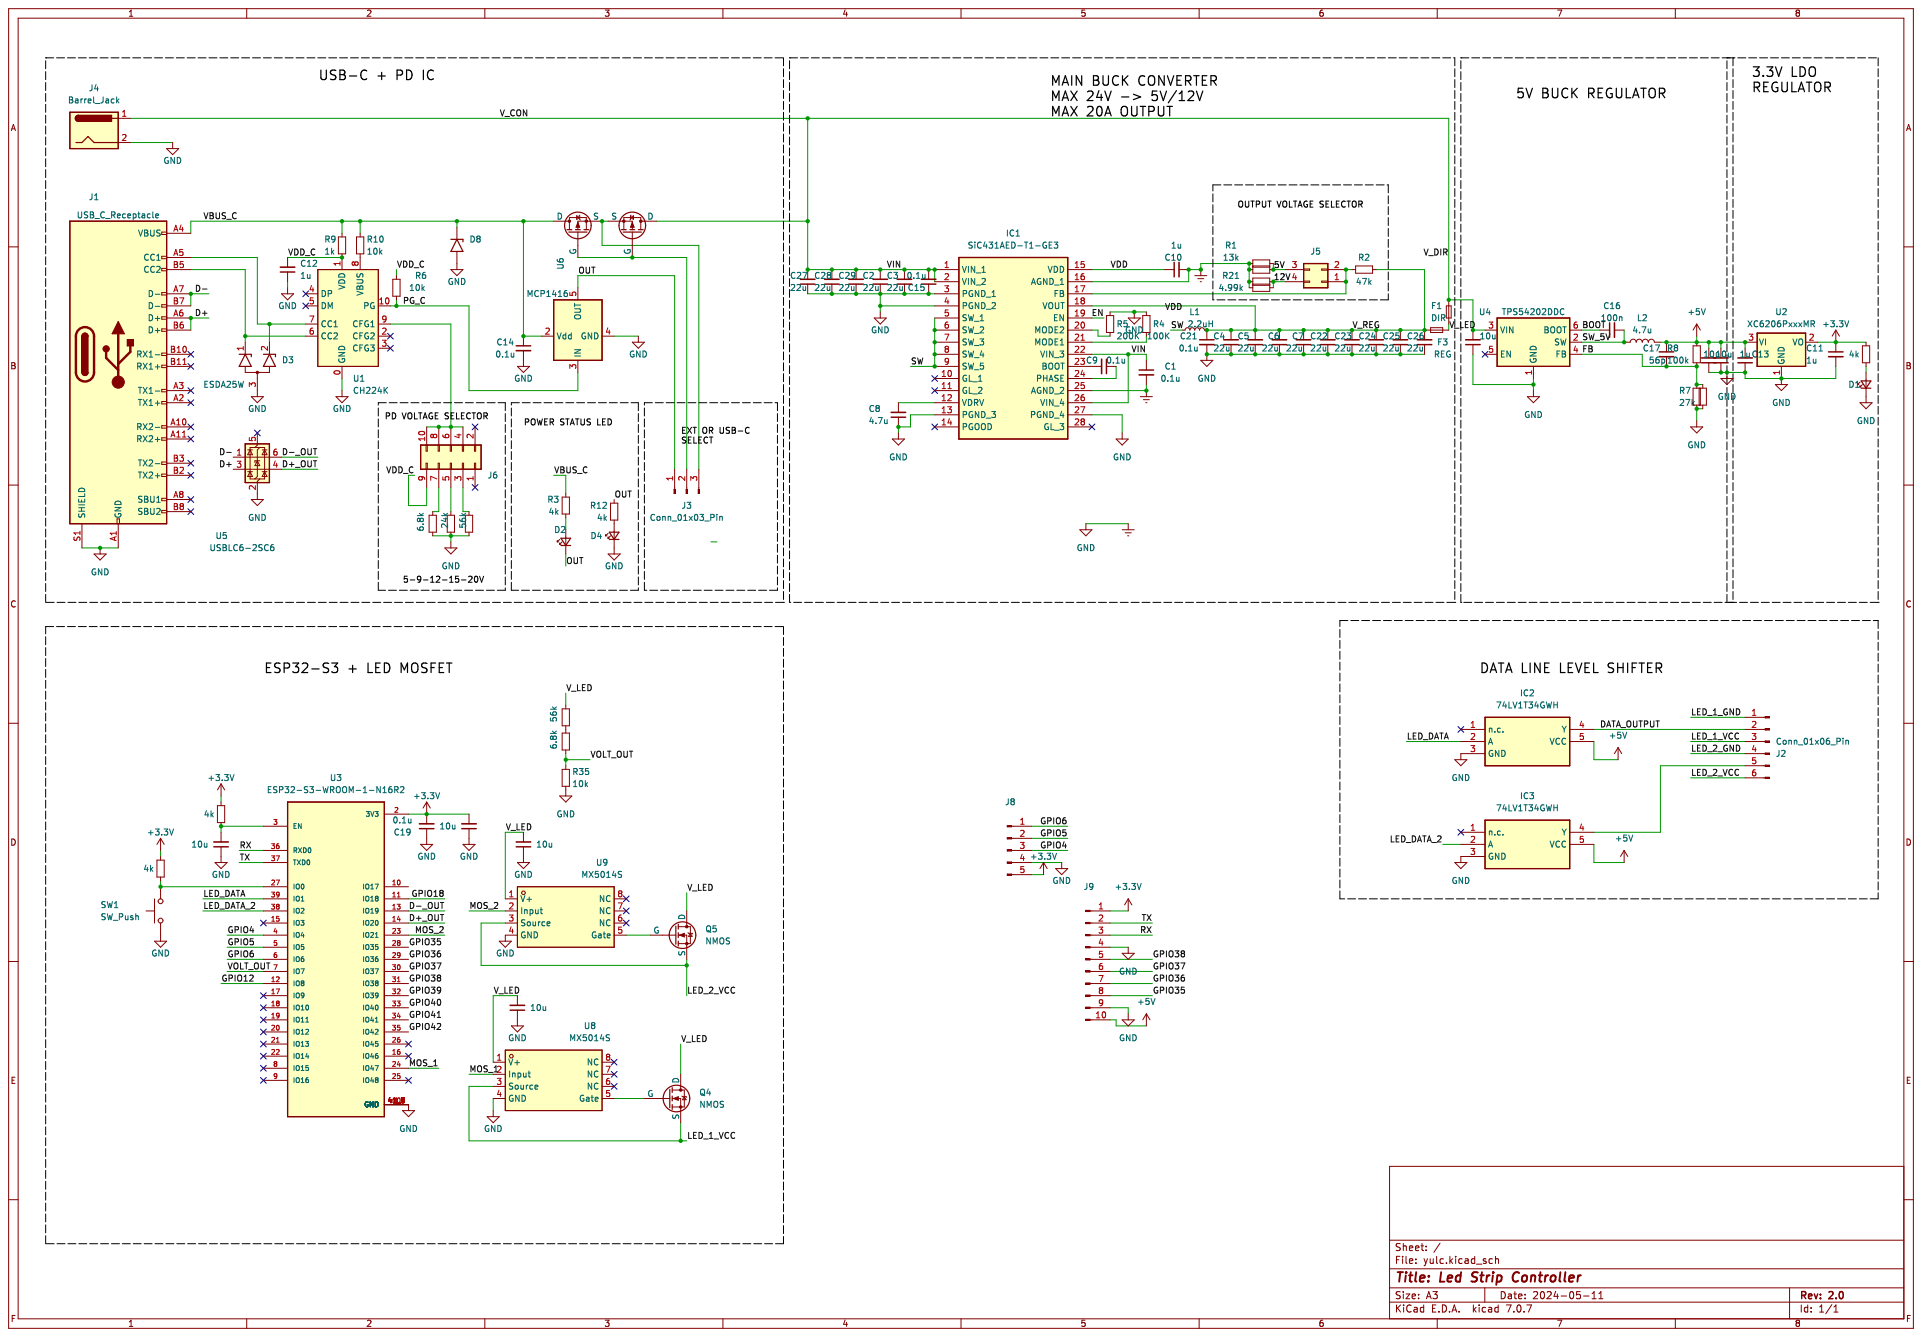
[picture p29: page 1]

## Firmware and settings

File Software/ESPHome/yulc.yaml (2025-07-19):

substitutions:
  name: yulc
  friendly_name: yulc
  project_name: aae.yulc
  project_version: '1.1'

esphome:
  name: ${name}
  friendly_name: ${friendly_name}
  min_version: 2024.6.0
  name_add_mac_suffix: false
  platformio_options:
    board_build.flash_mode: dio
  project:
    name: ${project_name}
    version: ${project_version}

esp32:
  board: esp32-s3-devkitc-1
  framework:
    type: arduino
    version: latest

psram:
  mode: quad
  speed: 80MHz

logger:

api:

ota:
- platform: esphome

improv_serial:

wifi:
  ap: {}

captive_portal:

dashboard_import:
  package_import_url: github://ale1800/YULC/Software/ESPHome/yulc.yaml@main
  import_full_config: true

esp32_improv:
  authorizer: none

web_server:

# Set up two addressable strips on pin GPIO1 and GPIO2
# If you want to use them, adjust the rgb_order, chipset, num_leds and name.
# On turn_on and turn_off they are already switched by the respective mosfet, ensuring no data transmission while power supply is disconnected 
light:
  - platform: fastled_clockless
    rgb_order: GRB
    chipset: WS2811
    pin: GPIO1
    num_leds: 60
    name: "Strip 1"
    id: strip_1_light
    on_turn_on:
      then:
        - output.turn_on: gpio_47
        - delay: 500ms
        - light.turn_on: strip_1_light
    on_turn_off:
      then:
        - light.turn_off: strip_1_light
        - delay: 500ms
        - output.turn_off: gpio_47
  - platform: fastled_clockless
    rgb_order: GRB
    chipset: WS2811
    pin: GPIO2
    num_leds: 40
    name: "Strip 2"
    id: strip_2_light
    on_turn_on:
      then:
        - output.turn_on: gpio_21
        - delay: 500ms
        - light.turn_on: strip_2_light
    on_turn_off:
      then:
        - light.turn_off: strip_2_light
        - delay: 500ms
        - output.turn_off: gpio_21

# Monitoring internal S3 temperaure sensor every 10s, in order to turn off both mosfet when the temperature rises above 70°C.
sensor:
  - platform: internal_temperature
    name: "Internal Temperature"
    update_interval: 10s
    id: internal_temp
    on_value:
      then:
        - if:
            condition:
              sensor.in_range:
                id: internal_temp
                above: 70
            then:
              - light.turn_off: strip_1_light
              - light.turn_off: strip_2_light
              - delay: 500ms
              - output.turn_off: gpio_47
              - output.turn_off: gpio_21
              
# Monitoring of voltage that is present on the terminal block, so likely the voltage that the strip is receiving (excluding voltage drobs at the end of the strip cable). If it drops below 1V, you'll se a "BLOWN FUSE" text in the web ui.
# It means a short-circuit or the fuse is not installed
  - platform: adc
    pin: GPIO7
    name: "Fuse Voltage"
    id: fuse_voltage
    update_interval: 1s
    attenuation: 11db
    filters:
      - multiply: 7.6
    on_value:
      then:
        - if:
            condition:
              lambda: 'return id(fuse_voltage).state < 1.0;'
            then:
              - logger.log: "BLOWN FUSE"
              - text_sensor.template.publish:
                  id: fuse_status
                  state: "BLOWN FUSE"
            else:
              - text_sensor.template.publish:
                  id: fuse_status
                  state: "Fuse OK"

output:
  - platform: gpio
    pin: 47
    id: gpio_47
  - platform: gpio
    pin: 21
    id: gpio_21

text_sensor:
  - platform: template
    name: "Fuse Status"
    id: fuse_status

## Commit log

2024-06-16 Add files via upload
    Added schematic
2024-08-08 Added kicad project
    [yulc.kicad_pcb, yulc.kicad_sch]
